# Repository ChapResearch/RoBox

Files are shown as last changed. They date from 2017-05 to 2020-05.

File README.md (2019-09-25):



# RoBox
You have found the Chap Research and Team Appreciate (FRC2468)
RoBox github, congratulations!

The RoBox project was started in the spring of 2017 with the
goal to create a programmable robot that would be affordable
for anyone. While there are great programmable robot kits
available, they are often simply too expensive for people
on a tight budget.

So we set out to create an open-source software/hardware
robot kit that would target $30.  We're not there yet,
but moving in the right direction.

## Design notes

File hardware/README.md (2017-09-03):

# RoBox Hardware

This section of the RoBox repository contains all production and previous version CAD models for the RoBox kit.

TODO: Add STLs and other 3d model filetypes for each model

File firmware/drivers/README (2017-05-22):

    ____                 ____  ___   
   / __ \___  ____ _____/ /  |/  /__ 
  / /_/ / _ \/ __ `/ __  / /|_/ / _ \
 / _, _/  __/ /_/ / /_/ / /  / /  __/
/_/ |_|\___/\__,_/\__,_/_/  /_/\___/ 

This directory includes the libraries that are used to compile the
RoBox source to the target devices. Currenty, there is only one
available "RoBoxRomeo". It contains the drivers for the peripheral
devices for the Romeo board.

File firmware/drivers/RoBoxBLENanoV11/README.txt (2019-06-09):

Important Notes
---------------

The implementation in this driver uses the following pins:

LEDs - A1
BLE - (serial port pins 0/1)
IR - IR1=8, IR2=9, BLAST=13
Motor - 1 - DIR=4, SPEED=5
        2 - DIR=7, SPEED=6
Speaker: 3
Line: A0
Ultra: trig=12, echo=11
Servo: 10

Arduino Pin Usage            Romeo Availability   NOTE
-----------------            ------------------ --------------------------------------------------------
0  - BLE/serial                     -
1  - BLE/serial                     - 
2  -                               yes
3  - Speaker                       yes          Change from previous - used to be on 10
4  - Motor 1 - DIR                  -
5  - Motor 1 - Speed (PWM)          -
6  - Motor 2 - Speed (PWM)          -
7  - Motor 2 - DIR                  -
8  - IR1                           yes
9  - IR2                           yes
10 - servo                         yes           New - used to be speaker
11 - ultra - echo                  yes
12 - ultra - trig                  yes
13 - IR Blaster                    yes
A0 - Line                          yes
A1 - LEDs                          yes
A2 - 
A3 - 

Arduino Timer Usage
-------------------

The Arduino (Atmega328) has three times, that can be connected to PWM pins.  The pin
capabilities are:

PWM PINS     TIMER
-----------  -----
Pins 5 & 6:  Timer0
Pins 9 & 10: Timer1
Pins 11 & 3: Timer2

In addition, existing Arduino libraries are wired to use timers as:

Timer0: delay(), millis(), and micros()

Timer1: servo library

Timer2: tone library

Specific Notes
--------------
BLE - uses the serial port to communicate to the BLE chip. The drive uses "command mode"
over the serial port to do things like setting the bluetooth name.  Note that different
firmware on the BLE chip defaults to different baud rates for the serial port. For the
Romeo it is 115200, and for the BLE-Nano it is 9600.  NOTE - this 9600 may change in the
future, that's pretty darn slow.

IR - "bit banging" is done.  Which means that when a send() is called, it won't return
until the send is complete. This all happens within micro seconds on the order of 100ms.
Upon recieve, the code quickly checks to see if there is a carrier around and if so, it
will go into the reading loop.

MOTOR - drives the motors using analogwrite() on the speed pin. Note that analogwrite()
uses the timer 0 and will potentially have higher than expected duty cycles due to
interaction with millis() and delay() functions. Because pins 5/6 are used for speed,
the PWM freq is 980Hz. (see arduino reference for analogWrite())

Speaker - the speaker driver is using pin 10 currently, but should really be moved to
pin 3.  Then 10 can be used for servo.

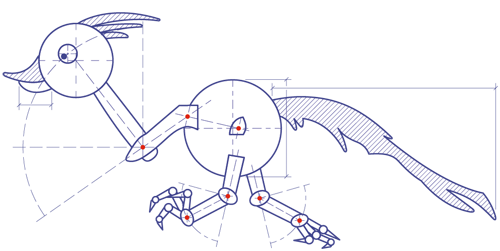
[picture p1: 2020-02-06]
Website/Main/media/CRbird.png

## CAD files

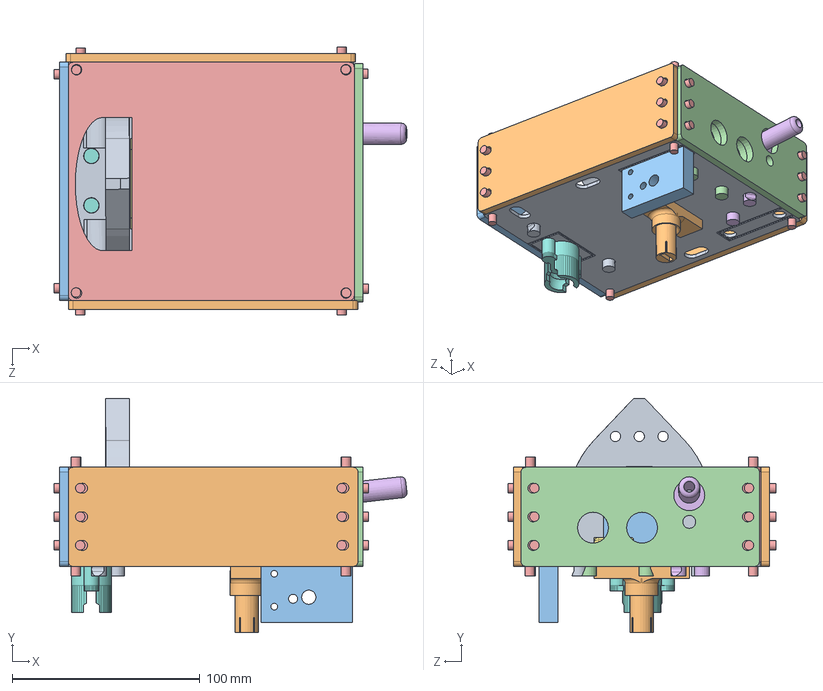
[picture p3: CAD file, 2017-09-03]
hardware/Robot/Production/MASTER ASSEMBLY.SLDASM
188.1 x 124.9 x 142.7 mm
Chassis - V7
Side Plate - V7 x 2
Back Plate - V7
Ultrasonic - V7
Lego - V8 x 3
Duck - V7
Romeo - V7
Caster - V7
Turret - V9
Line Follow - V8
Motor Mount - V13
Front Plate - V7
Roof

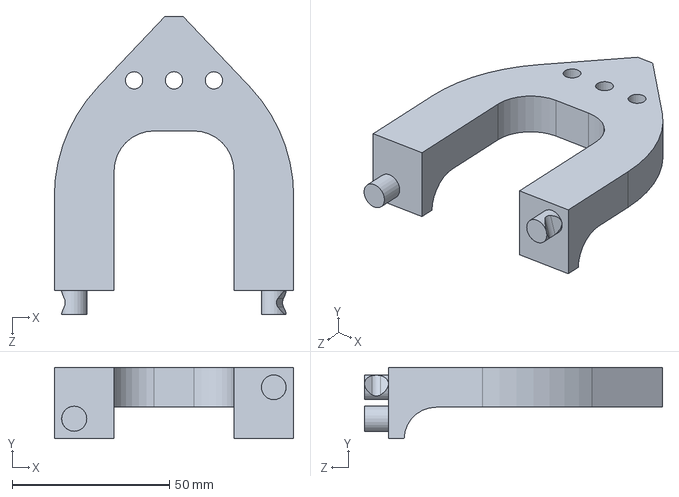
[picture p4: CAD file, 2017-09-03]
hardware/Robot/All Versions/Arch/Turret - V9.SLDPRT
76.2 x 22.7 x 94.8 mm

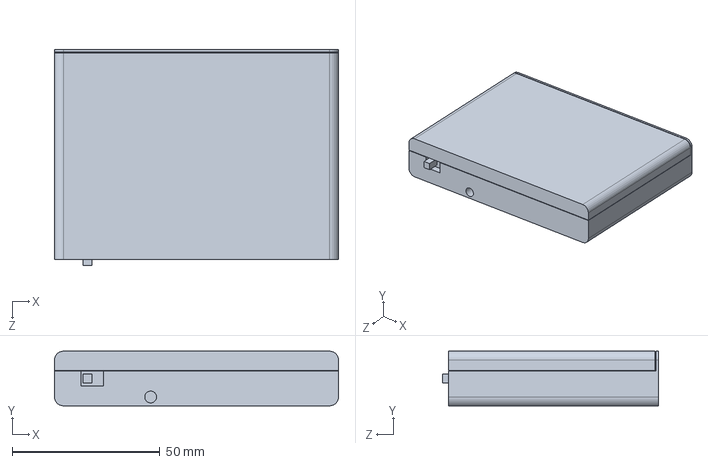
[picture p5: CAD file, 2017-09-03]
hardware/Robot/All Versions/BatteryCase/BATTERY CASE.SLDPRT
96.0 x 18.5 x 73.0 mm

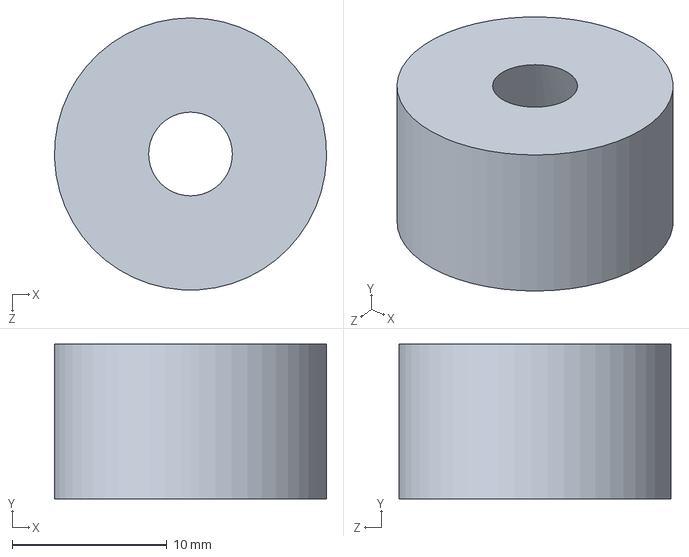
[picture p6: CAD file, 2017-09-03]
hardware/Robot/All Versions/Caster/CasterMount-V7.SLDPRT
17.6 x 10.0 x 17.6 mm

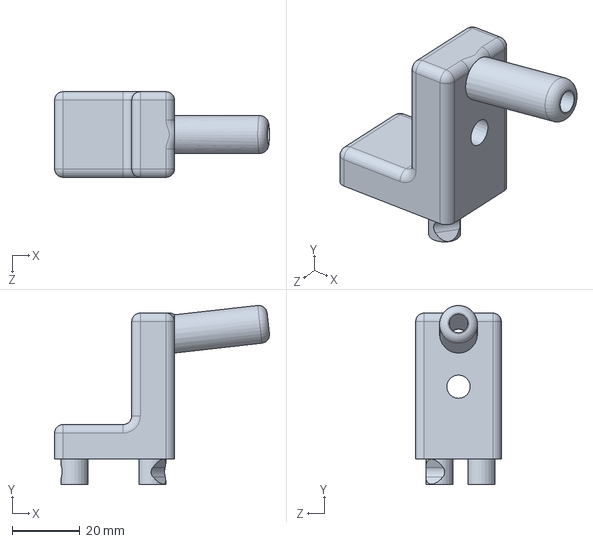
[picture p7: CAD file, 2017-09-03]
hardware/Robot/All Versions/Duck/Duck - V7.SLDPRT
63.7 x 53.0 x 25.4 mm

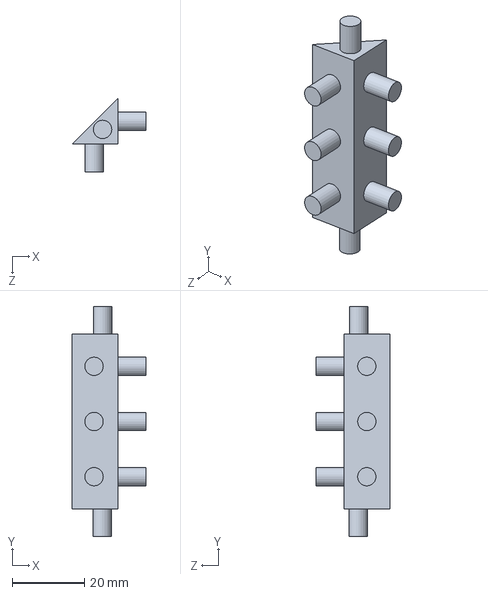
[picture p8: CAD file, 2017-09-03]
hardware/Robot/All Versions/Lego/Lego - V8.SLDPRT
20.3 x 63.5 x 20.3 mm

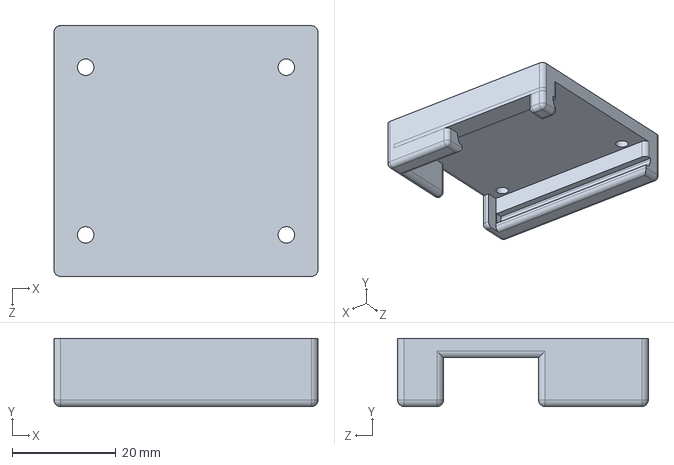
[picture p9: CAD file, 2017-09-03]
hardware/Robot/All Versions/RomeoMount/RomeoMount-V7.SLDPRT
50.8 x 13.1 x 48.3 mm

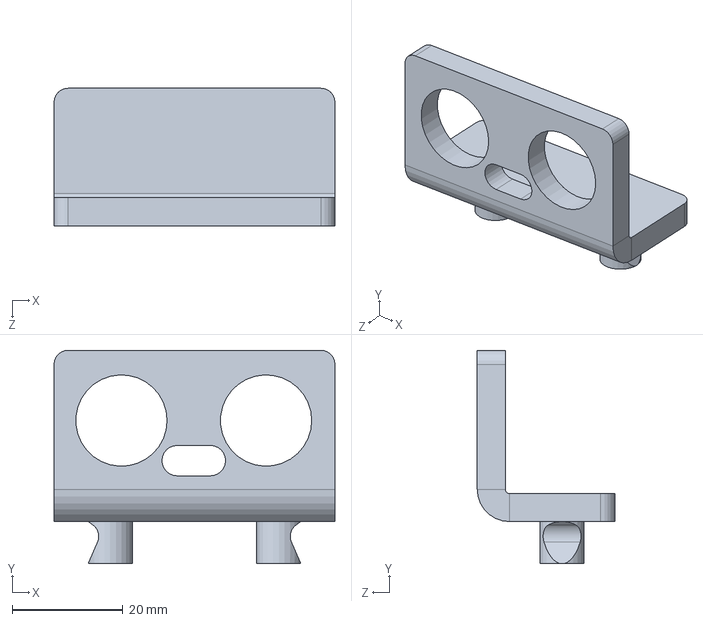
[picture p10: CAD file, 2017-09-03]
hardware/Robot/All Versions/Ultrasonic/Ultrasonic - V7.SLDPRT
50.8 x 38.6 x 24.9 mm

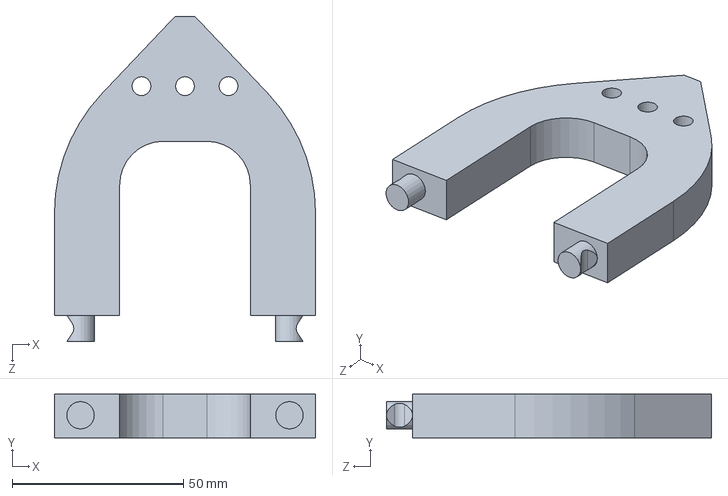
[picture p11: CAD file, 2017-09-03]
hardware/Robot/Production/Arch/Turret - V9.SLDPRT
76.2 x 12.7 x 94.8 mm

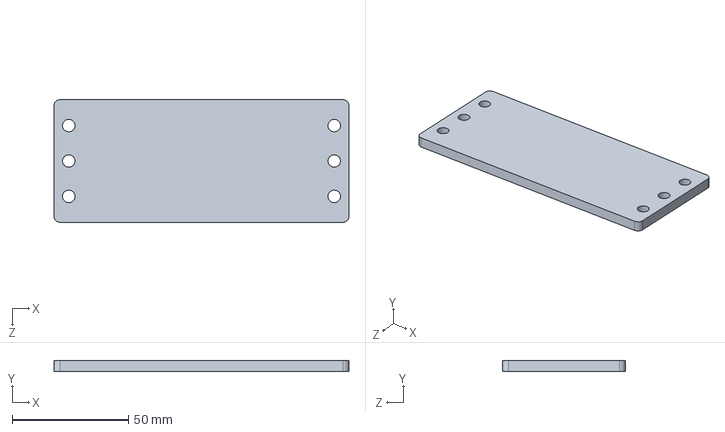
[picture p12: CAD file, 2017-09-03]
hardware/Robot/Production/BackPlate/Back Plate - V7.SLDPRT
127.0 x 4.76 x 52.8 mm

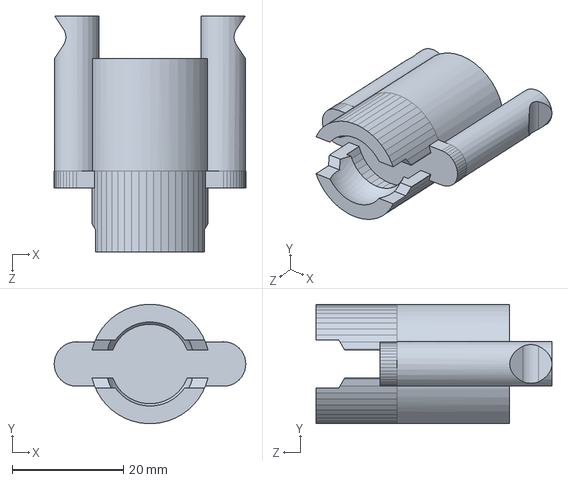
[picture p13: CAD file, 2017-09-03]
hardware/Robot/Production/Caster/Caster - v11.SLDPRT
34.5 x 21.5 x 42.5 mm

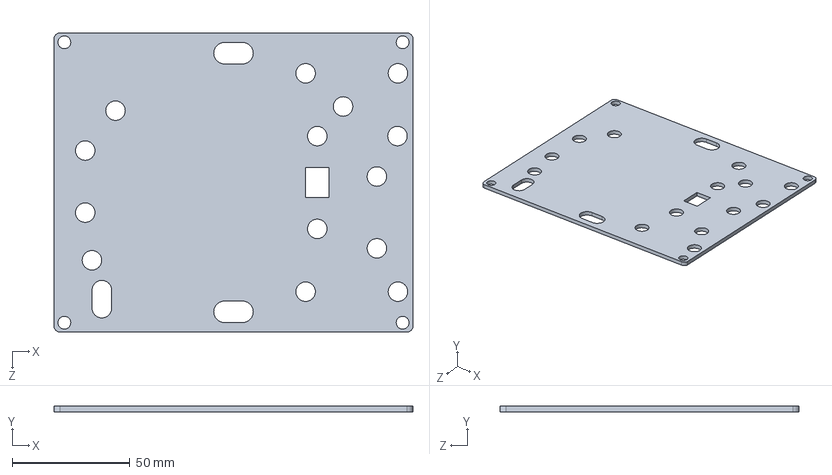
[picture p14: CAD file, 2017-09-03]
hardware/Robot/Production/Chassis/Chassis - V11.SLDPRT
152.4 x 2.36 x 127.0 mm

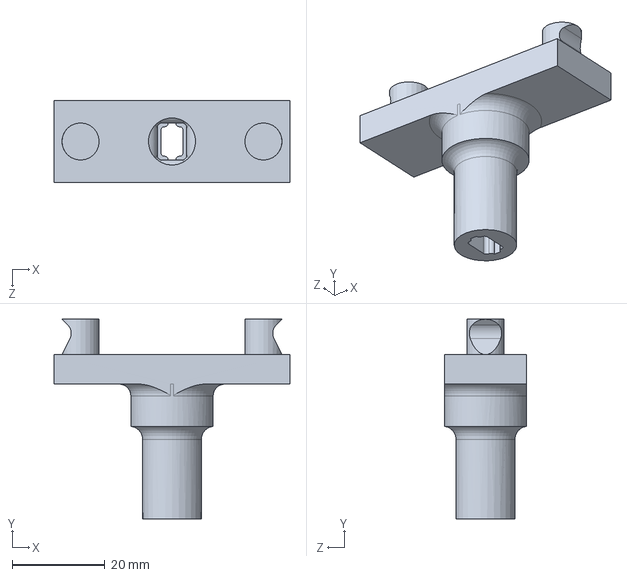
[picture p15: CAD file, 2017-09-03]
hardware/Robot/Production/LineFollowMount/Line Follow - V10.SLDPRT
50.8 x 43.0 x 17.7 mm

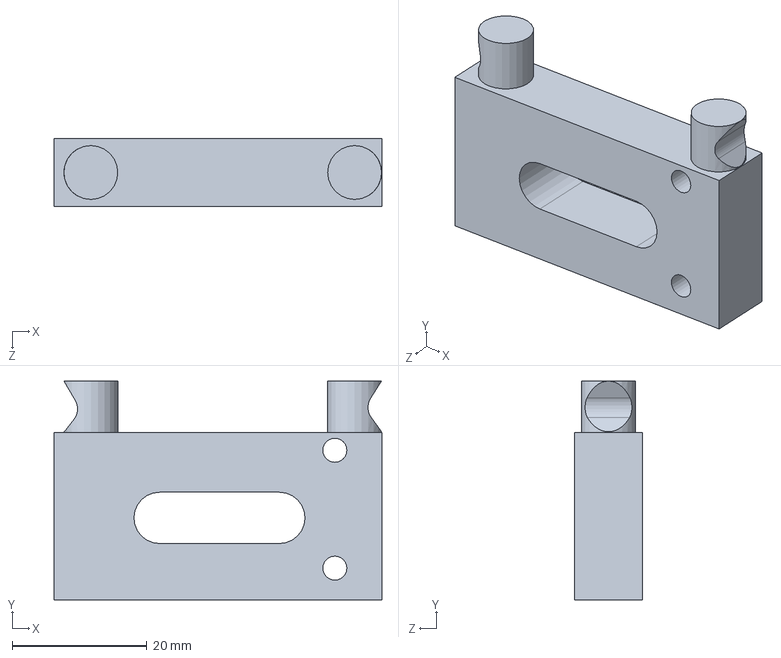
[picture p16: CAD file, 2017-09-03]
hardware/Robot/Production/MotorMount/Motor Mount - V15.SLDPRT
48.7 x 32.5 x 10.2 mm

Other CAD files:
hardware/Robot/Production/Duck/Duck - V8.SLDPRT
hardware/Robot/Production/FrontPlate/Front Plate - V7.SLDPRT
hardware/Robot/Production/RomeoMount/Romeo - V7.SLDPRT
hardware/Robot/All Versions/Arch/Turret - V7.SLDPRT
hardware/Robot/All Versions/Arch/Turret - V8.SLDPRT
hardware/Robot/All Versions/Caster/Caster - V10.SLDPRT
hardware/Robot/All Versions/Caster/Caster - V7.SLDPRT
hardware/Robot/All Versions/Caster/Caster - V9.SLDPRT
hardware/Robot/All Versions/Duck/TallAngryDuck-V8.SLDPRT
hardware/Robot/All Versions/Lego/Lego - V7.SLDPRT
hardware/Robot/All Versions/LineFollowMount/Line Follow - V7.SLDPRT
hardware/Robot/All Versions/LineFollowMount/Line Follow - V8.SLDPRT
hardware/Robot/All Versions/LineFollowMount/Line Follow - V9.SLDPRT
hardware/Robot/All Versions/MotorMount/Motor Mount - V11.SLDPRT
hardware/Robot/All Versions/MotorMount/Motor Mount - V12.SLDPRT
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

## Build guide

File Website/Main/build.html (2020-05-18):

Skip to main content

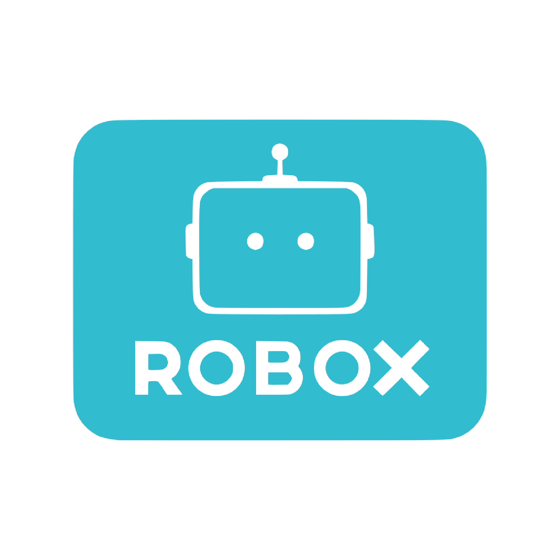
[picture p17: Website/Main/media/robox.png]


## Instructions

## Challenges

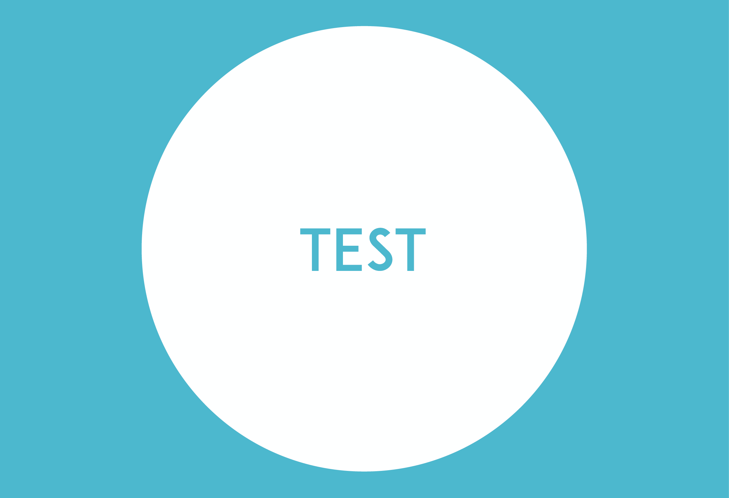
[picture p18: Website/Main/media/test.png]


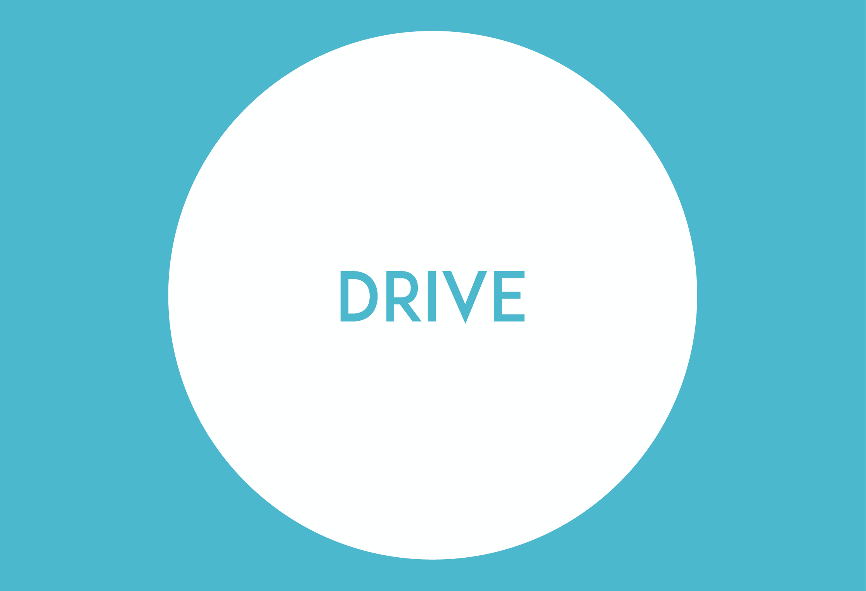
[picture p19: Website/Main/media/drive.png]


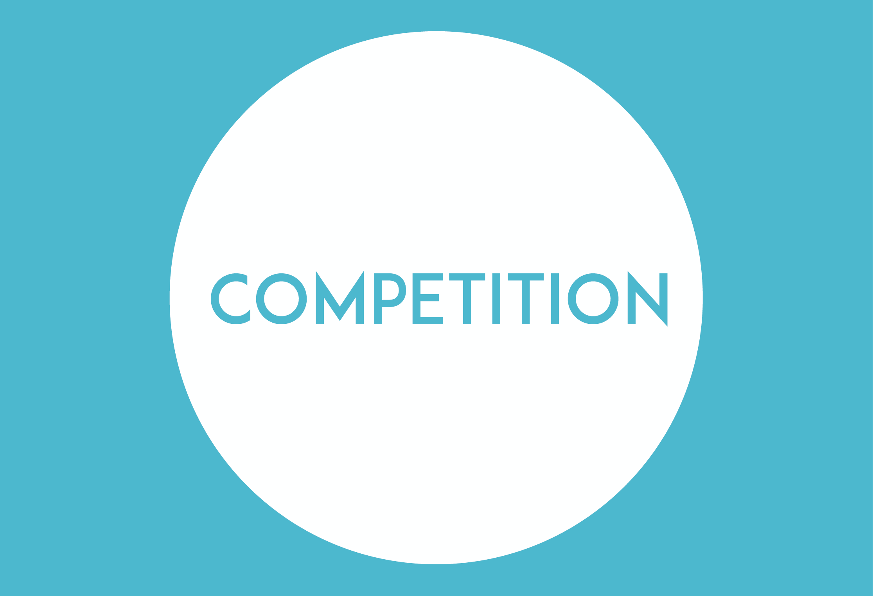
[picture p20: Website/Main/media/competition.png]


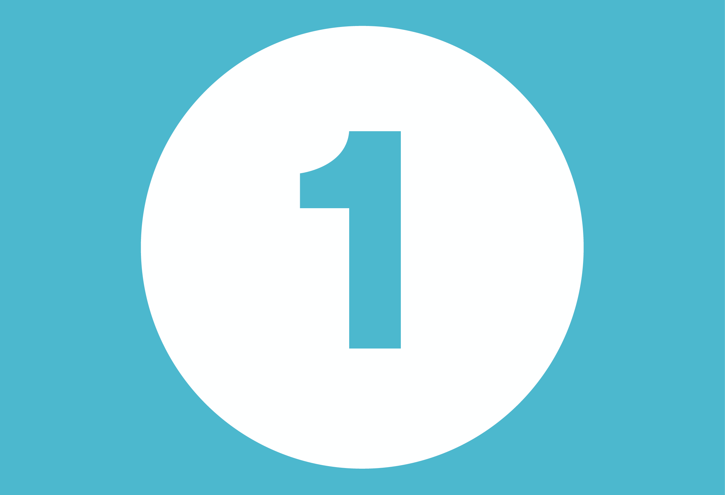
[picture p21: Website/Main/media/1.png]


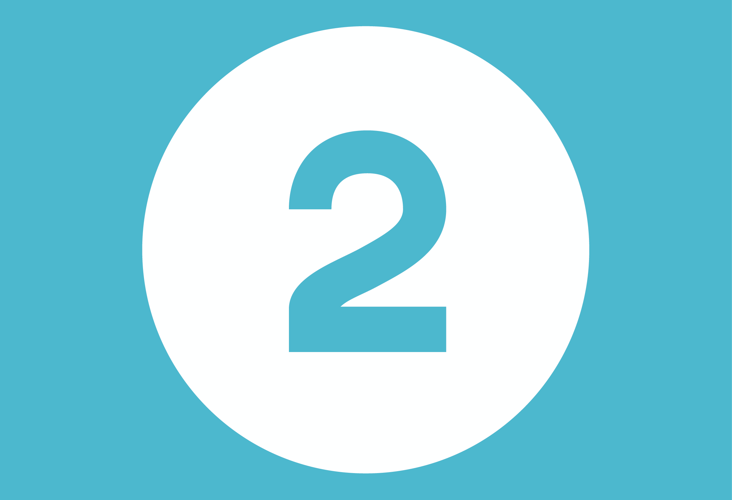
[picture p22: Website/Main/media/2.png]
Slice of cake


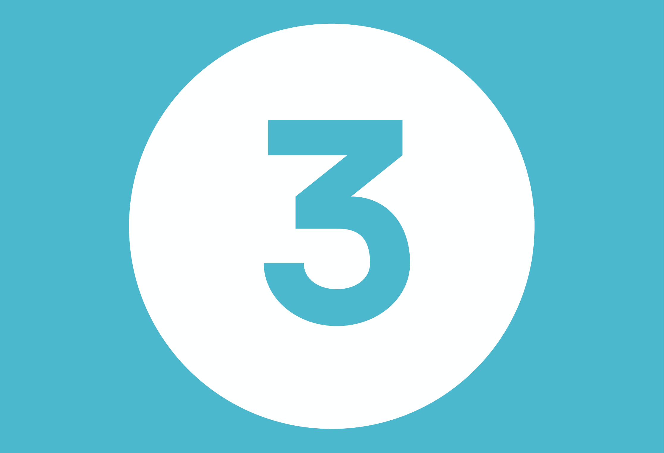
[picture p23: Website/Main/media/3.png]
Circus tent


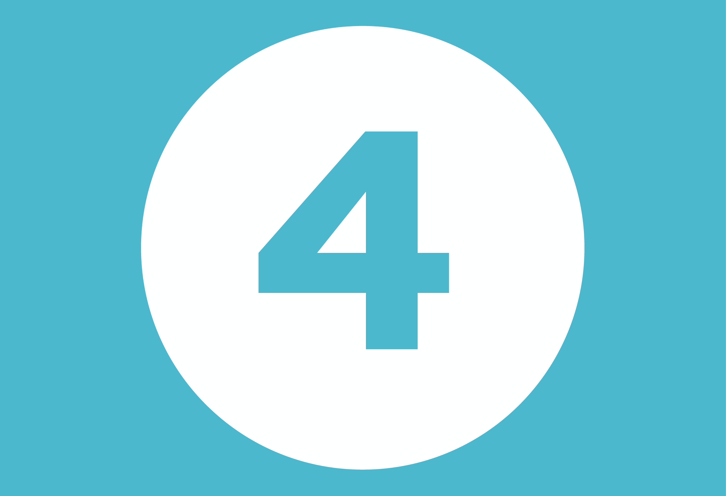
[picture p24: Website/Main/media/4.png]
Game controller


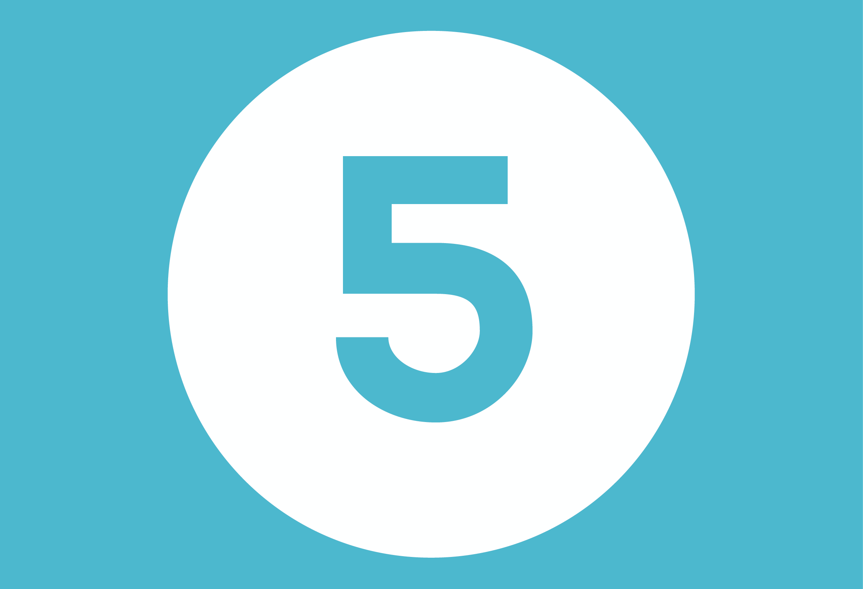
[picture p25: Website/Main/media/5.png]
Safe


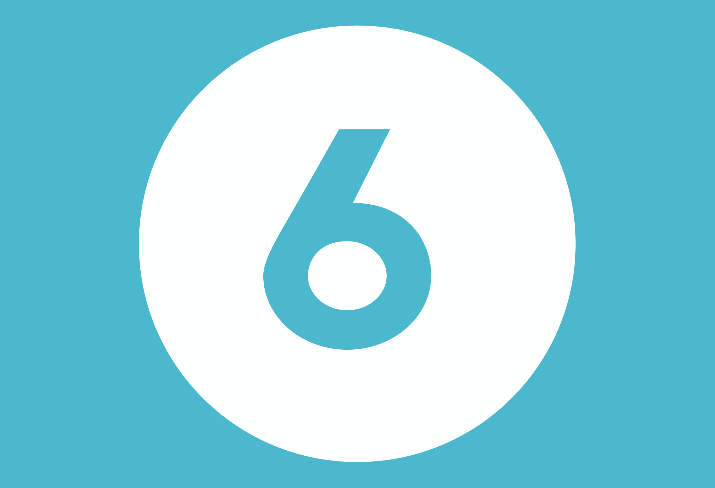
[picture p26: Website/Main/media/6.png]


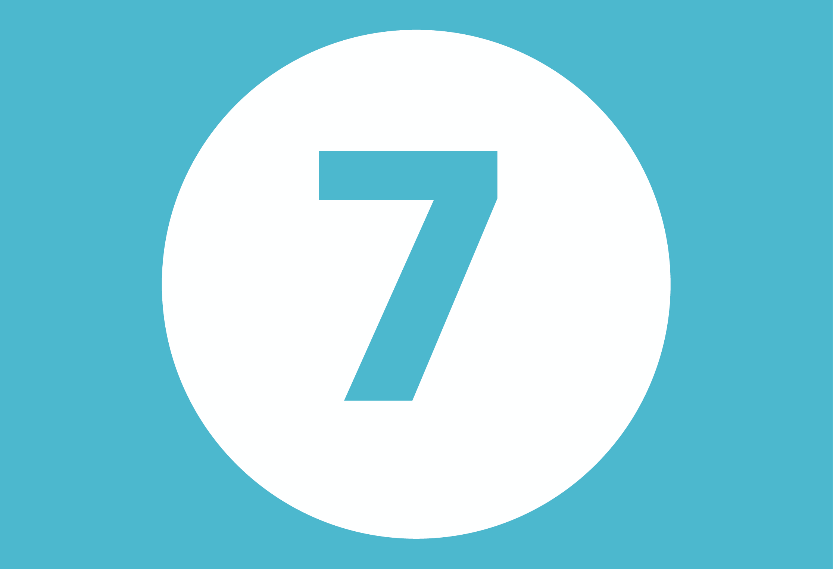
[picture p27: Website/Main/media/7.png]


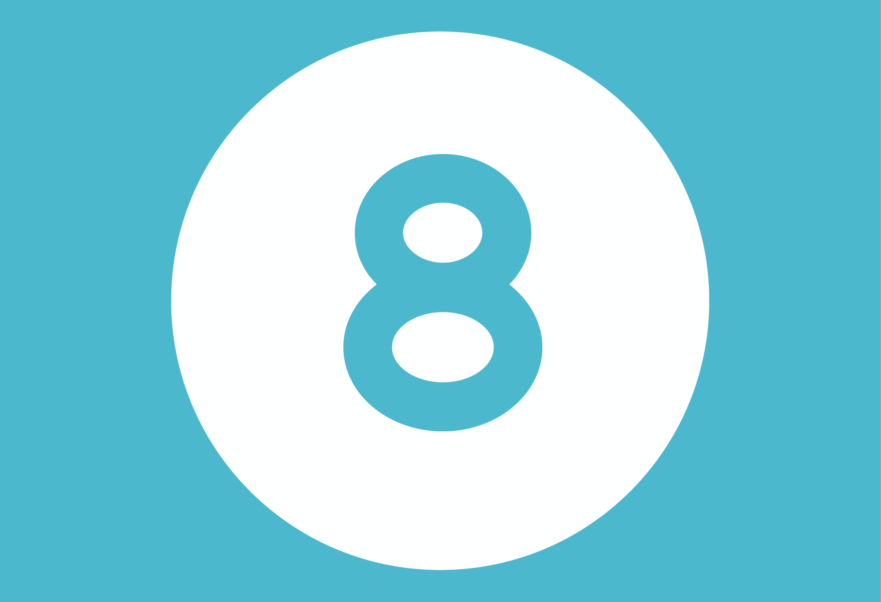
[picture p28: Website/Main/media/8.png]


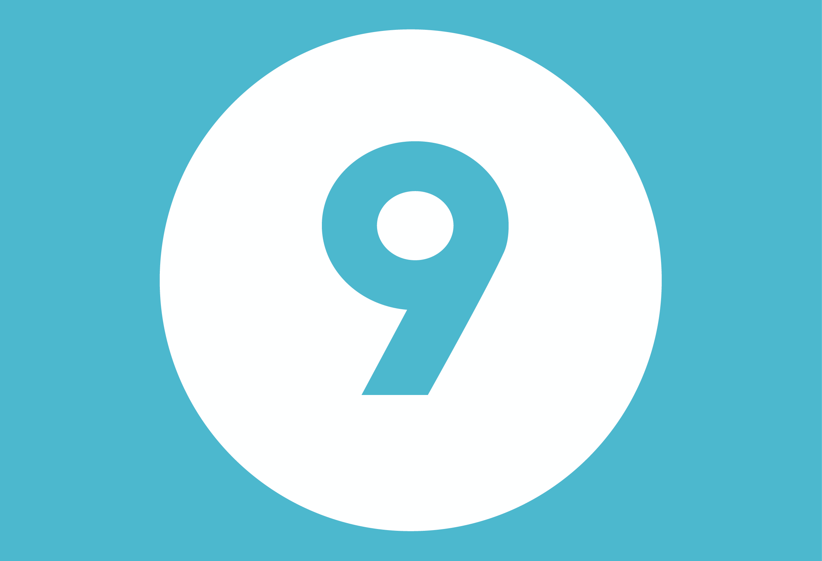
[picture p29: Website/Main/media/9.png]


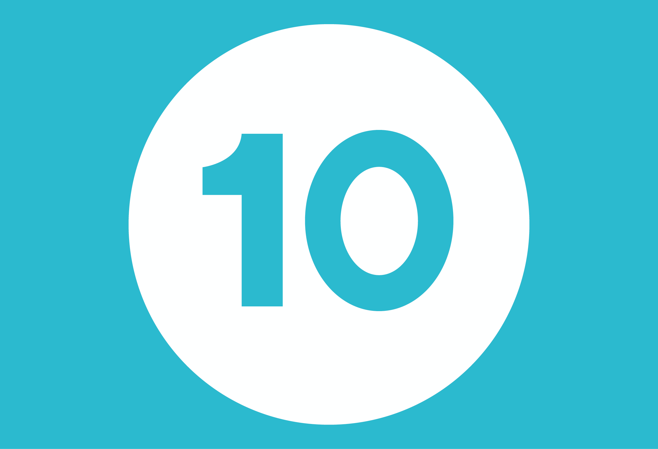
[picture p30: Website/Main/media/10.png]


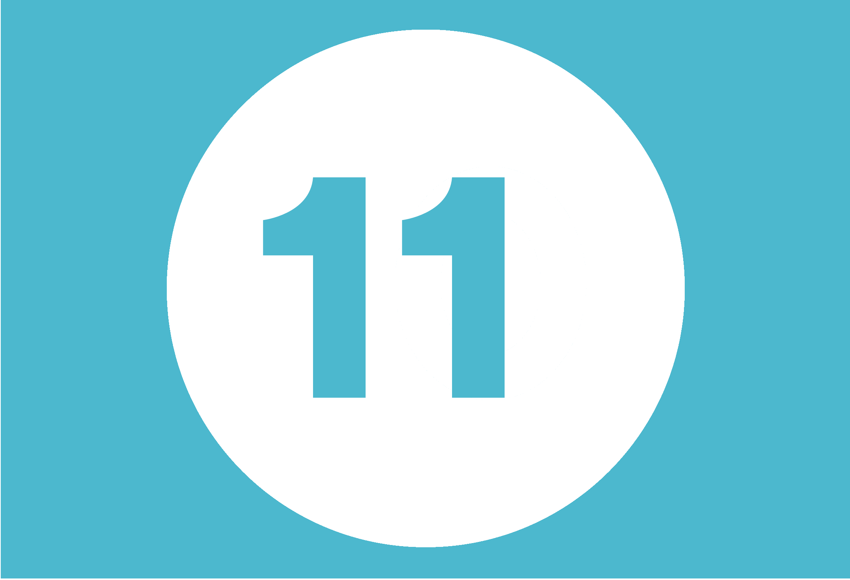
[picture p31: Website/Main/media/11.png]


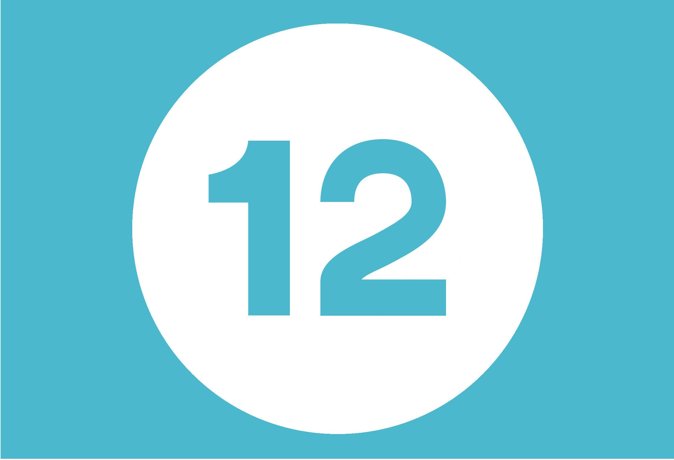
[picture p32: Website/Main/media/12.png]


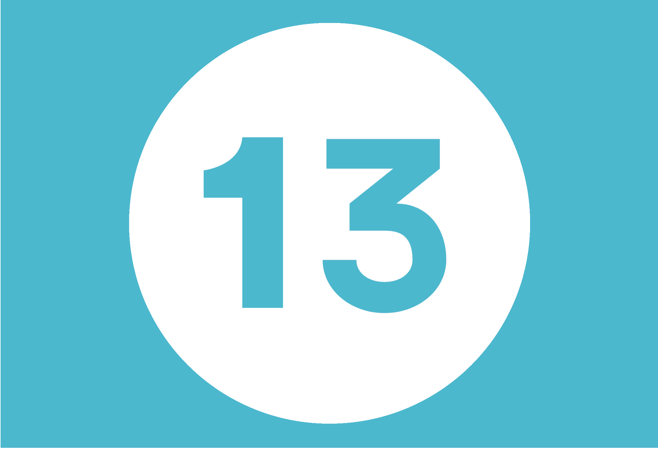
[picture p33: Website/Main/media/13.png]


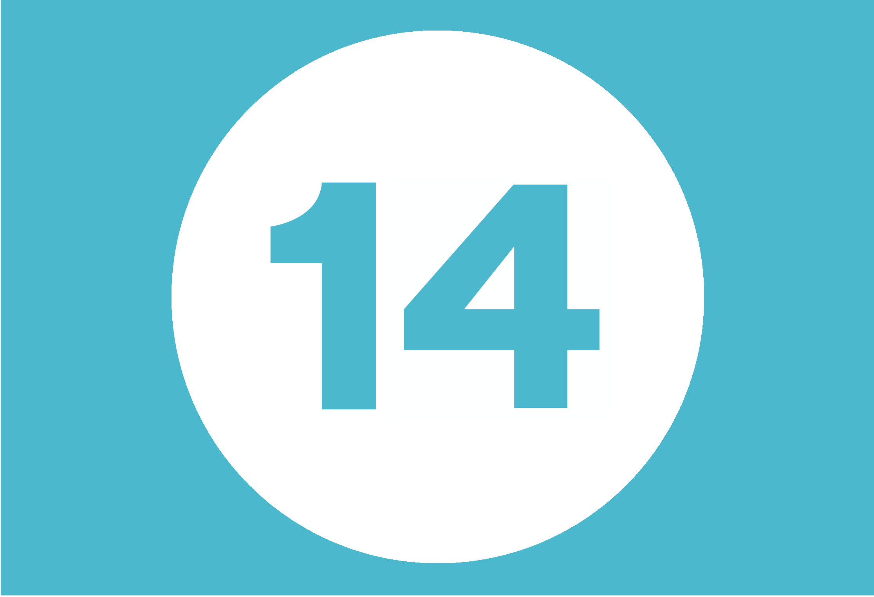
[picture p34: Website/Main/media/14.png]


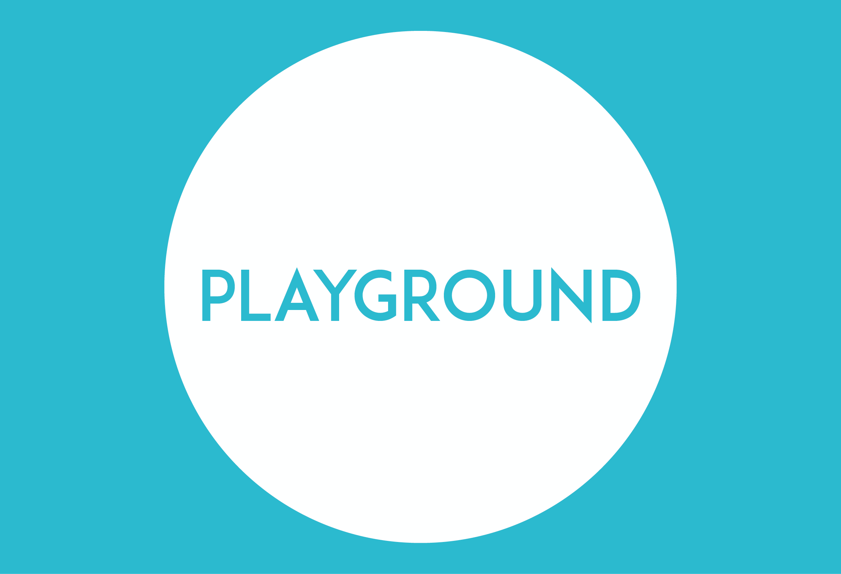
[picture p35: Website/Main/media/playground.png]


## Resources

### Blockly Games (https://blockly-games.appspot.com/)

### Lightbot (http://lightbot.com/flash.html)

### CodeCombat (https://codecombat.com/)

### Fantastic Contraptions (http://fantasticcontraption.com/original/)

## Parents

### Setup Instructions (https://docs.google.com/presentation/d/e/2PACX-1vSsZPUmgPDMVKf0CcLTnzA44kquYmY873SyItA2wyiORwoKejh-iZcBMK2ccgO7uJfCYBadEo5ZBmgn/pub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)

### Contact Us

### Around the Web

- Facebook (https://www.facebook.com/ChapResearch/)
- Twitter (https://twitter.com/ChapResearch)
- LinkedIn (https://linkedin.com/company/chap-research)
- Instagram (https://www.instagram.com/chapresearch/)

Copyright © RoBox 2018

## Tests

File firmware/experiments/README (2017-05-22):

    _______                                      
   / ____(_)________ ___ _      ______ _________ 
  / /_  / / ___/ __ `__ \ | /| / / __ `/ ___/ _ \
 / __/ / / /  / / / / / / |/ |/ / /_/ / /  /  __/
/_/   /_/_/  /_/ /_/ /_/|__/|__/\__,_/_/   \___/ 
                                                 
This is the main directory for the firmware that runs on the
RoBox itself. Included here is the main code for running the
robot as well as the code for driving the different peripherals
(sensors/motors/etc.) on the robot.  NOTE that the peripherals
MAY have different driving mechanisms depending upon the board
that is being used.

Currently we only use the Romeo board, so that is the only
one that is available. The directory "drivers" is where that
can be found.

These directories are organized to allow you to use both Windows
and Linux to compile Robox.  However, Linux is recommended, and
is currently the way in which the code is organized. But it
wouldn't take much work to use Windows.

LINUX
-----
To use linux, you need the following (see https://playground.arduino.cc/Linux/Mint
for more information):

- Arduino tool chain:

  	  sudo apt-get install arduino

- Arduino makefile
  	  
	  sudo apt-get install arduino-mk

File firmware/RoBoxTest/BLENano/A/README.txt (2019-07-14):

This tests half of the electronic components on the RoBox.
The components tested are:
    1. LEDs -- turns the three LEDs to a different color
    2. IR receivers -- turns LEDs on when IR blasts are received
    3. Line follow -- turns on a red, yellow, or green LED based on line follow reading

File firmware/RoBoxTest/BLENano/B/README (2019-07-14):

This tests half of the electronic components on the RoBox.
The components tested are:
    1. Speaker -- plays two pitches
    2. IR blasters -- sends out an IR blast
    3. Ultrasonic -- turns on either a red, yellow, or green LED based on reading of ultrasonic

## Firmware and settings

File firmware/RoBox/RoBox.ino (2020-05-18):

//     ____        ____            
//    / __ \____  / __ )____  _  __
//   / /_/ / __ \/ __  / __ \| |/_/
//  / _, _/ /_/ / /_/ / /_/ />  <  
// /_/ |_|\____/_____/\____/_/|_|  
//
//  This is the main RoBox controller program. It makes use of
//  everything else in drivers to implement the program.
//  So note that everything is NOT in this directory.
//

#include "Arduino.h"

// NOTE - the organization here is such that THIS file just includes
//        the "hardware.h" file and it includes all of the right
//        libraries based upon the Makefile configuration (and the
//        #defines therein). Any file needing access the the hardware
//        needs to include this file.
//
// NOTE - it is expected that the hardware is setup automatically
//        when the file is loaded. That is, nothing needs to be done
//        in the setup() routine.

#include "hardware.h"
#include "roboxMessage.h"
#include "RCL.h"
#include "IR.h"
#include "start_up_show.h"

// DEBUG DEBUG DEBUG 
//#include "SoftwareSerial.h"
//SoftwareSerial debugSerial(2,4);

// Set the send/receive functions for all members of the RoBoxMessage class

int (* RoBoxMessage::recvfn)() = hw_bleReceive;
void (* RoBoxMessage::sendfn)(byte*,int) = hw_bleSend;

// Incoming large/rename/program messages are stored in EEPROM beginning at this pointer

int RoBoxMessage::EEPROM_ptr = 0;

RoBoxMessage message;

void setup()
{
/// DEBUG DEBUG DEBUG DEBUG DEBUG DEBUG DEBUG 
//	debugSerial.begin(38400);

        hw_init();
	start_up_show();
}

void loop()
{
	static long	loopTracker = 0;
	loopTracker++;

	if (false)
	{	// DEBUG DEBUG DEBUG DEBUG DEBUG DEBUG DEBUG 
		// This block will toggle led #1 every N times through this loop

		if( (loopTracker % 5000) == 0) {
			hw_led(1,2);
		}
	}

	if(false) {	// DEBUG DEBUG DEBUG DEBUG DEBUG DEBUG DEBUG 
		// This block will send out line follow status every N times through this loop

		if( (loopTracker % 5000) == 0) {
			// creates a quite temporary message object and sends it immediately
			RoBoxMessage('U',hw_readUltraSonic()).Send();
		}
		if( (loopTracker % 5000) == 2500) {
			// creates a quite temporary message object and sends it immediately
			RoBoxMessage('L',hw_readLineFollow()).Send();
		}
	}

	if(message.Receive()) {

/// DEBUG DEBUG DEBUG DEBUG DEBUG DEBUG DEBUG 
//		debugSerial.print("-");
//		debugSerial.print(message.cmd,HEX);
//		debugSerial.print(message.length,HEX);
//		debugSerial.print(message.arg[0],HEX);
//		debugSerial.print(message.arg[1],HEX);

		// DEBUG DEBUG DEBUG (toggle LED when a message is received)
//		 hw_led(3,2);
		RCLIncoming(message,false);	// note that this routine will recursively call
		                                //   message.Receive() when running a program
	}

	// check for an IR hit

	{	uint32_t IRvalue;

		IRvalue = IRHit();
		if(IRvalue) {
			// DEBUG DEBUG DEBUG (toggle LED upon hit)
			// hw_led(2,2);
			RoBoxMessage('I',(IRvalue&0xff00)>>8,IRvalue&0x00ff).Send();
		}
	}

	// this needs to be called at the end of the loop() and will normally 
	//   do things such as keep a tone going or flash LEDs

	hw_update();
}

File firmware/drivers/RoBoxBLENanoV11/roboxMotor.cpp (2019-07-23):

//
// roboxMotor.cpp
//
//   Implements the interface to the motors on the RoBox.
//   This driver is specific for the BLE-Nano implementation.
//   It's ALMOST exactly the same as the Romeo V21, except that
//   the motor controller is slightly different (see below).
//
#include "Arduino.h"
#include "roboxMotor.h"

// Motors are controlled through an analogWrite on its speed
//   pin along with setting HIGH/LOW for direction.  Full speed is
//   255 and stopped is zero.  Note, though, that the polarity of speed
//   is reversed for direction=HIGH (meaning that 0 is full speed).

// for the BLENano, given our current board configuration, we
// switched what was M1 and what was M2

#define M1_SPEED_PIN	6
#define M1_DIR_PIN	7

#define M2_SPEED_PIN	5
#define M2_DIR_PIN	4

Motor::Motor(int motor)
{
     reverse = 0;
     pendingSpeed = 0;
     lastSpeed = 0;

     switch(motor) {
     case 1:
	  speed_pin = M1_SPEED_PIN;
	  dir_pin = M1_DIR_PIN;
	  break;
     case 2:
	  speed_pin = M2_SPEED_PIN;
	  dir_pin = M2_DIR_PIN;
	  break;
     }
     pinMode(speed_pin, OUTPUT);
     pinMode(dir_pin, OUTPUT);

}


//
// Reverse() - if the given argument evaluates to TRUE, then this motor will be
//             reversed. You can UN-reverse a motor by sending FALSE (zero);
//
void Motor::Reverse(int r)
{
     reverse = r;
}
void Motor::Reverse()
{
     reverse = !reverse;
}

//
// Speed() - sets the speed for this motor - see _speed().  This front-end ensures that
//           the motor delays between reverses of direction.
//
void Motor::Speed(int incoming_speed)
{

#define SIGNOF(x)	((x>0)?1:((x<0)?-1:0))
	
	if(incoming_speed != 0 && lastSpeed != 0) {	// if setting zero, or coming from zero, we're OK
		if(SIGNOF(lastSpeed) != SIGNOF(incoming_speed)) {
			_speed(0);			// turn OFF the motor prior to the delay
			pendingSpeed = incoming_speed;
			pendingTarget = millis() + _delay();
			return;				// no ACTUAL motor setting happens until after the delay
		}
		// if the signs are the same, we fall through and go ahead with the setting
	}

	// Note - this routine COULD be called multiple times before the pendingTarget is hit
	//   from a previous call.  Each call, therefore, will essentially reset the previous
	//   call through the above.  However, when setting zero, ensure we turn off pending.

	_speed(incoming_speed);
	lastSpeed = incoming_speed;
	pendingSpeed = 0;
}

//
// _delay() - returns an int of delay that should be observed, based upon the lastSpeed
//            in this object.
//
int Motor::_delay()
{
	// this function maps the last speed to a delay, with a minimum delay and a maximum

#define MOTORDELAY_MIN	50
#define MOTORDELAY_MAX	300

	return(map(abs(lastSpeed),0,100,MOTORDELAY_MIN,MOTORDELAY_MAX));
}
	

//
// _speed() - the internal call for ACTUALLY setting the speed for the motor.  Any delays
//            to accomodate the motor controller is implemented in the upper level Speed()
//            call.
//
//	      The speed is given between -100 and 100
//            inclusive, where negative numbers are reverse.  This number is translated
//            to the 0-255 value that is required for the motors.
//
void Motor::_speed(int incoming_speed)
{
     unsigned int speed;
     int	  forward;

     if(incoming_speed < 0) {
         forward = 0;
	 incoming_speed = -incoming_speed;
     } else {
         forward = 1;
     }

     if(incoming_speed > 100) {
	  incoming_speed = 100;
     }

     speed = 255 * incoming_speed / 100;		// translate to 0-255 - stays within 2 bytes

     if(reverse) {
	  forward = !forward;
     }

     if(forward) {
          speed = 255-speed;				// needed for new motor controller for BLE-Nano
	  digitalWrite(dir_pin,HIGH);
     } else {
	  digitalWrite(dir_pin,LOW);
     }
     analogWrite(speed_pin,speed);
}

void Motor::Stop(void)
{
	digitalWrite(speed_pin,LOW); 
}

//
// Update() - the motor controller we are using doesn't have short-circuit (break-before-make)
//            protection when reversing direction. So we have to build in a delay when reversing
//            direction, after setting the speed to zero.  This routine is called at the end of
//            each loop, and will check to see if the delay is over, and if so, execute the
//            pending settings.
//
void Motor::Update(void)
{
	// check to see if we have a pending speed, this means that it was a reverse of speed
	//   and that it can only be executed after the pendingTarget has been reached.
	
	if(pendingSpeed && pendingTarget < millis()) {
		_speed(pendingSpeed);
		lastSpeed = pendingSpeed;
		pendingSpeed = 0;
	}
}
	

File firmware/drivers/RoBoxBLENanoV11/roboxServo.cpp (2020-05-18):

//
// roboxServo.cpp
//
//    Implements the interface to the servo on the RoBox.
//    

#include <Arduino.h>
#include "roboxServo.h"

//
// Servos are controlled by PWM (pulse width modulation)
//   The duration of the pulse determines which position
//   the servo will travel to (generally measured in
//   microseconds from 1000 to 2000).
//

RoBoxServo::RoBoxServo()
{
  // maxTime and minTime are set by hardware_init
  #define PIN 10
  reverse = 0;
  targetMillis = 0;
  servo = new Servo;
  initialized = false;
}

//
// init() - (PRIVATE) - initializes the servo if it hasn't already been
//                      initialized.  See roboxServo.h for a explanation of
//                      why this is done.
//
void RoBoxServo::init()
{
  if(!initialized) {
    servo->attach(PIN);
    initialized = true;
  }
}

//
// Reverse() - if the given argument evaluates to TRUE, then this motor will be
//             reversed. You can UN-reverse a motor by sending FALSE (zero);
//
void RoBoxServo::Reverse(int r)
{
  reverse = r;
}
void RoBoxServo::Reverse()
{
  reverse = !reverse;
}

//
// Min() - Sets the experimentally determined minimum microseconds
//
void RoBoxServo::Min(int min)
{
  minTime = min;
}

//
// Max() - Sets the experimentally determined maximum microseconds
//
void RoBoxServo::Max(int max)
{
  maxTime = max;
}

//
// Rotate() - for continuous rotation servos, takes number from -100 to 100
//            negative numbers rotate counterclockwise, positive clockwise
//            magnitude is speed. 0 is where the servo stops. NOTE - it is up
//            to the caller to ensure that 0 stops by setting the min and max
//            of the servo.
//
void RoBoxServo::Rotate(int speed)
{
  init();
 
  targetMillis = 0; // setting to 0 is a flag so nothing will be done in Update()

  int microSeconds;

  if(reverse) {
    microSeconds = map(speed, -100, 100, maxTime, minTime);
  } else {
    microSeconds = map(speed, -100, 100, minTime, maxTime);
  }
  
  servo->writeMicroseconds(microSeconds);

}

//
// Rotate() - rotates at a certain speed (first parameter) for a certain
//            amount of time in milliseconds (second parameter)
//
void RoBoxServo::Rotate(int speed, int time)
{
  init();

  targetMillis = millis() + time;

  int microSeconds;
  
  if(reverse) {
    microSeconds = map(speed, -100, 100, maxTime, minTime);
  } else {
    microSeconds = map(speed, -100, 100, minTime, maxTime);
  }
  
  servo->writeMicroseconds(microSeconds);

}

//
// Position() - for non-continuous servos, takes a number from 0 to 100
//              0 takes the servo to its minimum degrees and 100 to its maximum
//
void RoBoxServo::Position(int pos)
{
  init();
 
  targetMillis = 0; // setting to 0 is a flag so nothing will be done in Update()

  int microSeconds;
  
  if(reverse) {
    microSeconds = map(pos, 0, 100, maxTime, minTime);
  } else {
    microSeconds = map(pos, 0, 100, minTime, maxTime);
  }
  
  servo->writeMicroseconds(microSeconds);

}

//
// Update() - checks to see whether the time for one complete rotation has
//            been met if a single shoot has been kicked off.
//            If so, keeps the servo rotating, otherwise turns it off
//
void RoBoxServo::Update()
{
  if(millis() > targetMillis && targetMillis != 0) {  
    Rotate(0);              // stops rotating the servo after the time for
                            // Rotate() has elapsed
    targetMillis = 0;       // setting to 0 is a flag so nothing will be
                            // done in Update()
  }
  
}

	

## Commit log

2017-05-22 massive reorganization of drivers and tests
2017-05-22 added ultrasonic and ultrasonic test
2017-06-07 Added motor driver and test
2017-06-07 updated ToneTest with correct pin and test device
    [ToneTest.ino]
2017-06-08 The driver and test for the LEDs
2017-06-13 Added toggle and blink to LEDs
2017-06-19 fixed the IR driver just a bit
    [roboxIR.cpp, roboxIR.h]
2017-06-19 fixed both IR makefiles to point to right device
2017-06-19 u-sonic makefile device fix
2017-06-19 added line follow driver and test
2017-07-18 added BLE as part of hardware drivers
2017-07-18 many minor changes to drivers for compilation
2017-07-18 moved tests into drivers
2017-07-23 removed LED monitoring of IR input
2017-07-23 driver support for BLE name changing
2017-07-23 fixed initialization of arm position - now doesn't skip first hit
2017-09-03 added cad models
2017-09-21 converted tone to use the Arduino tone function
2017-09-21 Motor work, not currently working for the make file
2017-09-21 first version of new motor
2017-09-24 moved to v2.0 and removed specific pin
2017-09-25 Changed motor driver for v2.0 Romeo BLE
2017-09-25 changed the IR send/recv pins to be in the driver
2017-09-25 changed to v2.0 of romeo and removed ref to tone pin
2017-09-25 move ultrasonic pins to in-driver
2018-06-14 New V2.1 of Romeo library that has new RGB LEDs
2018-06-14 test for new V2.1 of LED library
2018-06-19 added a flashing of lights and string of beeping to indicate that the RoBox is powered on
2018-07-13 Reversed right motor
2018-07-13 Upgraded to the latest driver version: 2.1
2018-07-13 Speaker plays based on variable values and sensor readings.
2018-07-13 Removed the debug LED indicators for functions
2018-07-13 Added code for the test board
2019-06-09 added BLE-Nano driver
2019-07-02 the new tests for BLE Nano board.
2019-07-14 reversed motors left/right
2019-07-23 added delay to motors for direction switch (cheap motor controller)
2019-07-29 fixed if/else problem my having each (sub)program have its own last_if_value, also bumped the minor version number
    [RXL.cpp]
2019-10-03 fixed typo in elseif and bumped VM version number
    [RXL.cpp]
2020-04-30 Initial commit of the RoBoxBLENanoV11 driver version
2020-04-30 Initial commit of the servo test
2020-05-01 fixed the problems with servo initialization - see roboxServo.h for more information
    [roboxServo.cpp]
2020-05-03 reorganized the robox drivers moving the selection of the driver into the Makefile all files now simply refer to roboxDrivers.h and each makefile causes linking to the selected driver note, too, that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
2020-05-18 new driving picture with new shooter buttons, new testing buttons for the shooter (start fire, stop fire, and fire once) added shadows and button animatations added rcl and rxl for the shooter added 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
2020-05-18 Added the button to go to challenge 14 on the camper page
2020-05-18 Added start and stop shoot Reorganized hardware init Pointed the Makefile at the latest drivers
2021-01-12 fixed servo stopping bug in RCL run and stop
    [RCL.cpp]
2021-01-12 fixed servo shoot to make one full revoluion
    [hwblenano.cpp]
2021-01-12 fixed servo not rotating appropriatly 65 seconds after boot
2021-04-24 added new HUD interface and prototype firebase usage
2021-05-04 deleted save button and associated methods
2021-05-08 updated hud.js to update the database to changes in the session. Removed extraneous send button on index.html
2021-05-17 removed showSensor checkbox. Added "pingDatabase" function which switches a new database key "activityPinger" in an active session between true and false every 3 seconds.
2021-05-26 programmed checkboxes and next-previous buttons, and renamed 'peek' to 'screenshot'
2021-05-31 added button to launch mentor gui
2021-06-02 moved next, previous, and launch mentor gui buttons to respective checkboxes, added functionality to next/previous buttons, HUD now watches to see that remote connection doesnt time out.
2026-07-12 updated the workspace save to use the Blocky-provided call
    Previously it was using mouseUp on the blocklyDiv, but that seems to
    have been eaten by other Blockly structures (except a couple). The
    Blockly call is far better.
